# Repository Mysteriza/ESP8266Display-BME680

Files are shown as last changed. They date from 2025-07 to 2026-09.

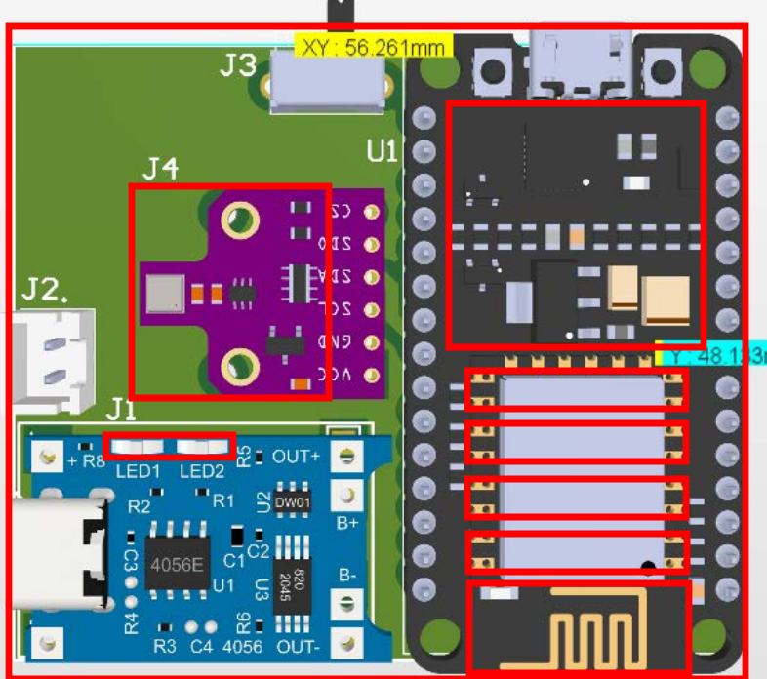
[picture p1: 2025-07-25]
Enclosure/Top Enclosure.png

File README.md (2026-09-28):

# High-Precision ESP8266 BME680 Environmental Monitor

A high-precision, portable environmental monitor using an ESP8266, a Bosch BME680 sensor, and an integrated OLED display. This project leverages the official **Bosch BSEC (Bosch Sensortec Environmental Cluster) software library** to provide accurate Indoor Air Quality (IAQ) readings, alongside temperature, humidity, pressure, and altitude.

The device is designed for **continuous operation** with robust error handling, intelligent baseline management, and an **always-on OLED display** that continuously cycles through data screens.



ESP8266 Device Front View
ESP8266 Device Side View
ESP8266 Device Rear View
ESP8266 Device Side View

---

## Key Features

### Core Sensing & IAQ

- **Bosch BSEC Integration:** Utilizes Bosch's proprietary BSEC algorithm for reliable **Indoor Air Quality (IAQ)** index calculation (0–500 scale).
- **Comprehensive Data:** Measures Temperature, Humidity, Barometric Pressure, Gas Resistance (VOCs), and calculates Altitude.
- **Data Persistence:** Saves the BSEC calibration state to EEPROM every **4 hours**, but only when the IAQ accuracy level is high (`iaqAccuracy==3`). This minimizes flash wear and ensures stable calibration across power cycles.

### Advanced Data Processing

- **Variance-Aware IAQ Smoothing:** Implements an adaptive smoothing algorithm on the Static IAQ value, providing a more stable and human-readable output.
- **Self-Adapting Gas Baseline:** Automatically adapts over time for long-term environmental stability.
- **Transport-Aware Logic:** Freezes baseline calibration when rapid environmental changes are detected (e.g., device movement).
- **Altitude Filtering:** Combines a median filter with an EMA for smooth and reliable altitude readings.

### Display & Power

- **Continuous Display Mode:** OLED display remains active 24/7, cycling through four data screens:
  - **Screen 1 (5s):** Temperature & Humidity
  - **Screen 2 (5s):** Pressure & Altitude
  - **Screen 3 (5s):** Gas Resistance, IAQ, Accuracy, Air Quality Status
  - **Screen 4 (5s):** System Uptime (HH:MM:SS)
- **Incremental Refresh:** Screen only updates when values change beyond thresholds, reducing flicker and CPU usage.
- **Battery Optimized:** Sensor reads every 30 seconds with intelligent power management for 24hr+ battery life.

### Overheat Protection

- If temperature ≥ **45°C**, device enters "HOT HOLD" mode.
- OLED shows a warning with a thermometer icon and the text **Overheat**, which shifts position every 60s to prevent burn-in.
- Normal operation resumes when temperature drops below **41°C**.

### Robustness

- **Error Recovery:** Auto-retry mechanism for BSEC initialization with exponential backoff.
- **Offline Operation:** Continues to work without network, using last known QNH or default fallback.
- **Serial Command Interface:** Configure QNH, check status, and calibrate altitude via serial monitor.

---

## Hardware Components

- **ESP8266 Board with Integrated OLED (0.96" SSD1306).**
- **Bosch BME680 Sensor** (I2C).
- **TP4056** for LiPo battery charging and management.
- **LiPo Battery** (e.g., 1500–2100 mAh).
- **Power Switch** for on/off control.
- **Custom PCB & Enclosure** for portability.

---

## Pin Configuration

| Component | Pin / Address |
| --- | --- |
| I2C SDA (Data) | `GPIO 14` |
| I2C SCL (Clock) | `GPIO 12` |
| OLED I2C Address | `0x3C` |
| BME680 I2C Address | `0x76` |

---

## Software Requirements

- Arduino IDE
- ESP8266 Board Package for Arduino IDE
- Libraries:
  - `Wire.h` (Built-in)
  - `EEPROM.h` (Built-in)
  - `Adafruit GFX Library`
  - `Adafruit SSD1306`
  - `Bosch BSEC Software Library`

---

## ⚠️ Important: IRAM Overflow Fix

If you encounter this compilation error:

```
section `.text1' will not fit in region `iram1_0_seg'
```

This is a **memory configuration issue**, not a code problem. The fix requires two settings changes:

### Quick Fix (Arduino IDE)

1. **Tools** → **Flash Size** → Change to `4M (3M SPIFFS)`
2. **Tools** → **MMU** → Select `16KB cache + 48KB IRAM`
3. **Restart Arduino IDE**

### Complete Guide

See **[FIX_IRAM_OVERFLOW_GUIDE.md](FIX_IRAM_OVERFLOW_GUIDE.md)** for:

- Detailed step-by-step instructions
- VS Code / PlatformIO configuration
- Manual `platform.txt` replacement method
- Troubleshooting and technical explanations

**Included in this project:** `platform.txt` (ready-to-use replacement file)

---

## Installation & Setup

1. **Install Arduino IDE & ESP8266 Core:**
   Add `http://arduino.esp8266.com/stable/package_esp8266com_index.json` to Board Manager URLs.

2. **Install Required Libraries** via Library Manager:
   - "Adafruit GFX Library"
   - "Adafruit SSD1306"
   - "BSEC Software Library"

3. **Configure the Sketch:**

   ```cpp
   // Edit configuration constants in config.h
   #define SENSOR_READ_INTERVAL_MS 30000UL    // Sensor reading interval
   #define OLED_DATA_SCREEN_1_DURATION 5000UL // Screen 1 duration
   #define OLED_DATA_SCREEN_2_DURATION 5000UL // Screen 2 duration
   #define OLED_DATA_SCREEN_3_DURATION 5000UL // Screen 3 duration
   #define OLED_DATA_SCREEN_4_DURATION 5000UL // Screen 4 (Uptime) duration
   ```

4. **Upload to ESP8266:**
   - Go to `Tools > Board` and select "NodeMCU 1.0 (ESP-12E Module)"
   - **Tools > Flash Size** → `4M (3M SPIFFS)`
   - **Tools > MMU** → `16KB cache + 48KB IRAM`
   - Connect your board and select the correct COM port
   - Click "Upload"

---

## Usage in the Field

### 🔹 Calibration via QNH (when local QNH data is available)

1. Connect your Android phone to the device via **USB-C OTG + data cable**.
2. Open **Serial USB Terminal** (or any compatible terminal app).
3. Set baud rate to **115200**, newline to **CR+LF**.
4. Type:
   ```
   QNH=1013.25
   ```
   (Adjust this to the latest QNH in your location. Check weather apps such as [Breezy Weather](https://github.com/breezy-weather/breezy-weather) for current atmospheric pressure)

The device stores QNH in EEPROM and immediately recalculates altitude.

### 🔹 Calibration via ALTREF (when you know the exact elevation)

1. Stand at a location with a verified elevation (e.g., summit, basecamp, map marker).
2. Type:
   ```
   ALTREF=709
   ```
   (Adjust this according to the altitude of your location)

The device computes QNH from the current pressure and saves it permanently. Verify with:

```
ALT?
```

### 🔹 Hiking / Trekking Scenario

- At **basecamp**, perform one calibration (QNH **or** ALTREF).
- Recalibrate if the weather changes significantly.
- **Precision Rule:** ±**1 hPa** ≈ ±**8–9 m** at mid-altitudes. Recalibrate whenever you change location or weather conditions vary.

---

## How It Works

### IAQ (Indoor Air Quality) Index

The BSEC library provides an IAQ value on a scale from 0 to 500:

- **0 - 50:** Excellent
- **51 - 100:** Good
- **101 - 150:** Lightly Polluted
- **151 - 200:** Moderately Polluted
- **201 - 300:** Heavily Polluted
- **301+:** Severely Polluted

The device displays this scale as an "AQS" (Air Quality Status) string for easy interpretation. The `Acc` (Accuracy) value indicates the BSEC algorithm's confidence level (0=stabilizing, 1=low, 2=medium, 3=high). High accuracy is typically achieved after the device runs for a while.

### Serial Commands

Connect via serial monitor (115200 baud) and use:

| Command | Description | Example Response |
| --- | --- | --- |
| `QNH=<hPa>`  | Set sea-level pressure | `OK QNH=1013.25 hPa` |
| `QNH?` | Query current QNH value | `QNH=1013.25 hPa` |
| `ALT?` | Query current altitude | `ALT=708.9 m` |
| `PRESS?` | Query current pressure | `P=933.10 hPa` |
| `ALTREF=<m>` | Auto-calculate QNH from known altitude | `OK QNH from ALTREF -> 1014.32 hPa` |
| `STATUS` | Show system status | `Mode:0 Therm:0 BSEC:Y IAQ:45.2(3)` |
| `HELP` | Show all commands | `CMD: QNH=<hPa>\|QNH?\|ALT?\|...` |

### Display Screens

The OLED continuously cycles through 4 screens:

1. **Screen 1 (5s):** Temperature & Humidity
2. **Screen 2 (5s):** Pressure & Altitude
3. **Screen 3 (5s):** Gas Resistance, IAQ, Accuracy, AQS
4. **Screen 4 (5s):** System Uptime (HH:MM:SS since boot)
5. **Loops back to Screen 1** → Continuous monitoring mode

### IAQ Scale

| IAQ Range | Air Quality |
| --- | --- |
| 0-50 | Excellent |
| 51-100 | Good |
| 101-150 | Light |
| 151-200 | Moderate |
| 201-300 | Unhealthy |
| 301+ | Hazardous |

### IAQ Accuracy

The `Acc` value (0-3) shows BSEC algorithm confidence:

- **0:** Stabilizing (first 5-30 minutes)
- **1:** Low confidence
- **2:** Medium confidence
- **3:** High confidence (optimal)

---

## Power Management

### Display Behavior

- **Continuous Mode:** Display never turns off
- **4 screens cycle** every 5 seconds each (20s total cycle)
- **Conditional redraw:** Only updates when values change beyond thresholds (reduces flicker)

### Battery Life Estimates

| Battery Capacity | Estimated Runtime |
| --- | --- |
| 1500 mAh | ~24-30 hours |
| 2000 mAh | ~30-36 hours |
| 2100 mAh | ~32-40 hours |

_Estimates based on continuous display mode with 30s sensor intervals_

---

## Advanced Features

### Thermal Protection

When temperature reaches **45°C**:

- Display shows animated "Overheat" warning
- Contrast reduced to minimum (prevents OLED damage)
- Warning icon position changes every 60s (prevents burn-in)
- Normal operation resumes at **41°C**

### Transport Detection

The device detects movement via rapid environmental changes:

- Freezes gas baseline calibration during transport
- Resumes calibration after 6 stable readings
- Prevents false VOC readings during relocation

### Adaptive IAQ Smoothing

IAQ display uses variance-adaptive filtering:

- **Low variance** (stable): Heavy smoothing (α=0.10) for stable reading
- **High variance** (changing): Light smoothing (α=0.45) for responsiveness
- **Accuracy-based:** Reduces smoothing when accuracy is low

---

## Accuracy Notes

- **Formula:** Based on the standard barometric equation. Real-world temperature deviations may cause small altitude offsets.
- **Sensor Tolerance:** BME680 pressure bias ≈ ±1 hPa → ±8–9 m error.
- **Weather Impact:** QNH drifts naturally with weather; recalibrate as needed during extended outdoor sessions.

---

## Troubleshooting

### ⚠️ IRAM Overflow Error (Compilation Error)

**Symptoms:**

```
section `.text1' will not fit in region `iram1_0_seg'
Compilation error: exit status 1
```

**Solution:** This is a memory configuration issue, NOT a code problem.

**Quick Fix:**

1. **Arduino IDE:**
   - Tools → Flash Size → Change to `4M (3M SPIFFS)`
   - Tools → MMU → Select `16KB cache + 48KB IRAM`
   - Restart Arduino IDE
2. **VS Code:**
   - Edit `.vscode/arduino.json`
   - Change `eesz=1M64` → `eesz=4M3M`
   - Change `mmu=3232` → `mmu=4816`
   - Reload window

**Complete Guide:** See [`FIX_IRAM_OVERFLOW_GUIDE.md`](FIX_IRAM_OVERFLOW_GUIDE.md) for detailed instructions and manual `platform.txt` replacement method.

### BSEC Initialization Fails

**Symptoms:** "Sensor Error" screen, "Retrying..."

**Solutions:**

1. Check I2C wiring (GPIO14=SDA, GPIO12=SCL)
2. Verify BME680 address (0x76 or 0x77)
3. Check serial monitor for error messages
4. Power cycle device

### IAQ Accuracy Stays at 0-1

**Cause:** BSEC needs time to stabilize

**Solution:** Leave device running for 30 minutes - 24 hours for full calibration

### Display Flickers

**Cause:** Normal when values change frequently

**Solution:** Adjust thresholds (`TH_T`, `TH_H`, etc.) to reduce update frequency

### EEPROM Corruption

**Symptoms:** Settings reset on reboot

**Solution:** Device auto-detects and repairs corrupted EEPROM

---

## Code Structure

```
ESP8266Display-BME680.ino   (setup + main loop)
└── src/
    ├── config.h             (all #defines, memory map)
    ├── types.h              (enumerations)
    ├── globals.h / .cpp     (global state variables)
    ├── utils.h / .cpp       (utility functions: baro, IAQ categories)
    ├── display/
    │   └── oled.h / .cpp    (OLED display + state machine)
    ├── sensing/
    │   ├── sensor.h / .cpp  (BSEC/BME680, thermal, error recovery)
    │   └── storage.h / .cpp (EEPROM persistence)
    └── communication/
        └── serial_cmd.h / .cpp (serial parser, char buffer)
```

---

## Project Files

| File | Description |
| --- | --- |
| `ESP8266Display-BME680.ino` | Main entry point (setup + loop) |
| `src/config.h` | Hardware & algorithm configuration constants |
| `src/types.h` | Enum type definitions |
| `src/globals.h` / `src/globals.cpp` | Global state variables |
| `src/utils.h` / `src/utils.cpp` | Utility functions (barometric, math, categories)  |
| `src/display/oled.h` / `src/display/oled.cpp` | OLED display & screen state machine |
| `src/sensing/sensor.h` / `src/sensing/sensor.cpp` | BSEC/BME680 driver, filtering, thermal, retry |
| `src/sensing/storage.h` / `src/sensing/storage.cpp` | EEPROM persistence layer |
| `src/communication/serial_cmd.h` / `src/communication/serial_cmd.cpp` | Serial parser (char buffer) |
| `platform.txt` | Fixed platform configuration for IRAM fix |
| `FIX_IRAM_OVERFLOW_GUIDE.md` | Complete IRAM overflow fix guide |
| `Pin.txt` | I2C wiring reference |
| `README.md` | This file - project documentation |

---

## Performance Metrics

### Memory Usage (Typical)

- **Flash:** ~290 KB code (measured build, varies with libraries)
- **SRAM:** ~34 KB (measured build)
- **EEPROM:** 512 bytes (~175 used: BSEC state + QNH + gas baseline)

### Timing

- **Boot Time:** ~2 seconds to first reading
- **BSEC Stabilization:** 5-30 minutes
- **Sensor Read Cycle:** 30 seconds
- **Display Cycle:** 20 seconds (4 screens, continuous loop)

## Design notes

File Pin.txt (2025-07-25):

I2C address 0x3C (OLED Display)

BME680 (0x76):
SDA = D5 / GPIO14
SCL = D6 / GPIO12
SDO = GND
CS = Not Connected

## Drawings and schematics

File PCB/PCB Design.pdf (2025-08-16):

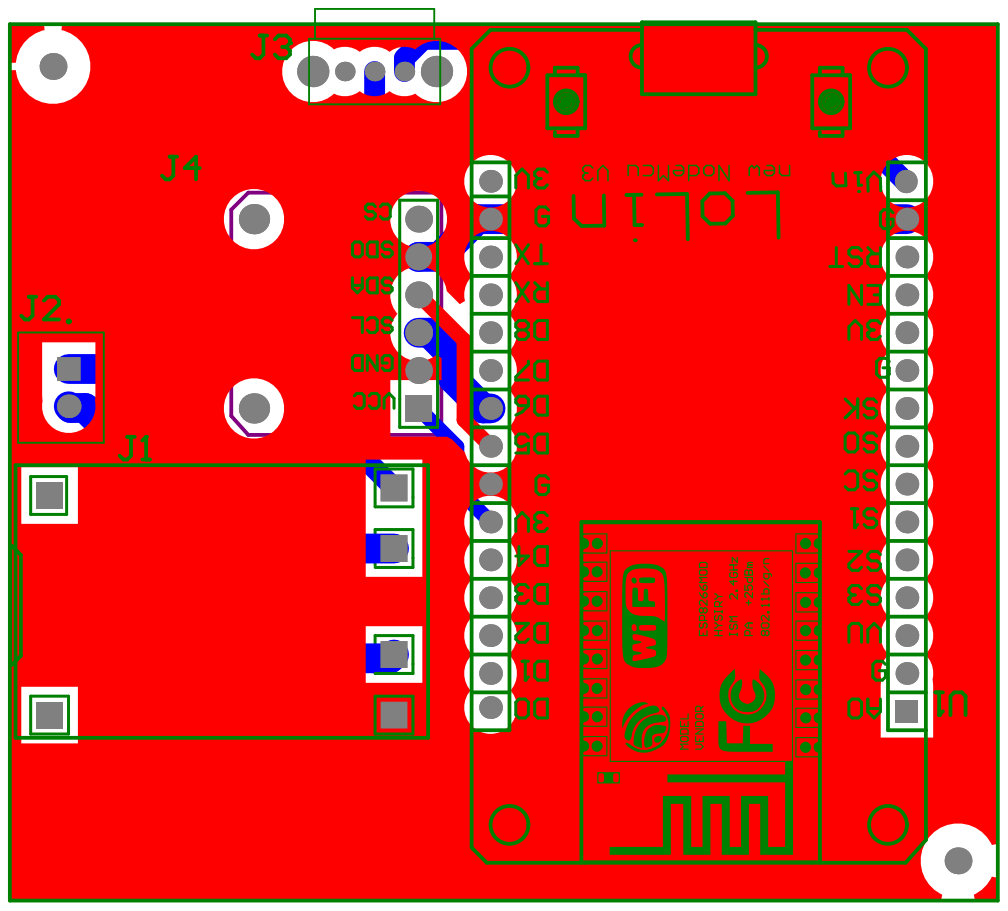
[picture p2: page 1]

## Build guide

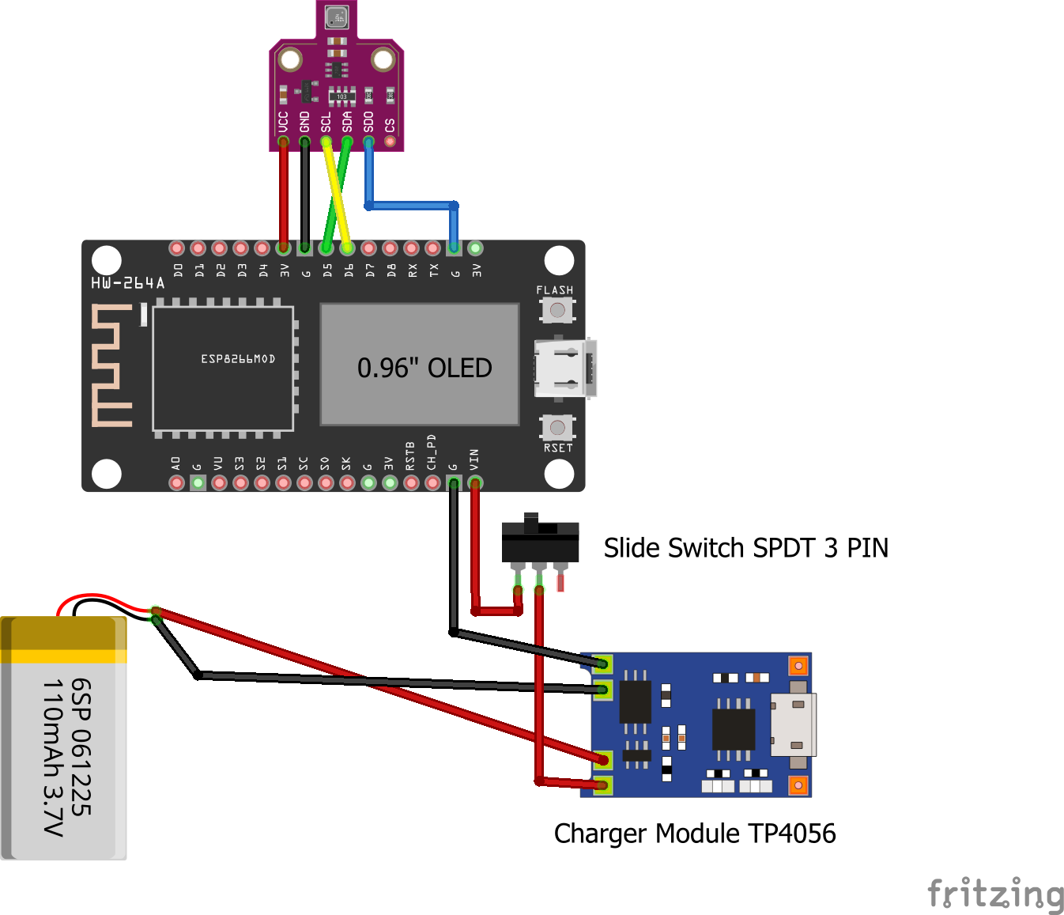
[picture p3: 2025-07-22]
PCB/Wiring ESP8266-BME680.png

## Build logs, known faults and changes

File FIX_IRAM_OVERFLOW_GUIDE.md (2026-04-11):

# ESP8266 IRAM Overflow Fix - Complete Guide

## Problem

When compiling ESP8266 projects with large libraries (especially **Bosch BSEC** for BME680), you get this error:

```
c:/users/.../xtensa-lx106-elf/bin/ld.exe: 
ESP8266Display-BME680.ino.elf section `.text1' will not fit in region `iram1_0_seg'
collect2.exe: error: ld returned 1 exit status
exit status 1
Compilation error: exit status 1
```

**Root Cause:** The ESP8266 has limited IRAM (Instruction RAM). The default configuration only allocates **32KB IRAM**, which is insufficient for large libraries like Bosch BSEC + Adafruit GFX + OLED drivers.

---

## Solution Overview

This fix requires **TWO changes**:

1. ✅ **Change Flash Size** → From 1MB to 4MB
2. ✅ **Change MMU Setting** → Enable 16KB Cache + 48KB IRAM

Both must be applied together for the fix to work.

---

## Method 1: Via Arduino IDE (Recommended for Beginners)

### Step 1: Change Flash Size

1. Open your project in **Arduino IDE**
2. Go to **Tools** menu
3. Find **Flash Size**
4. Change from `1M (64K SPIFFS)` → **`4M (3M SPIFFS)`** or `4M (1M SPIFFS)`

### Step 2: Change MMU Setting

1. Still in **Tools** menu
2. Find **MMU** (Memory Management Unit)
3. Select **`16KB cache + 48KB IRAM`** (sometimes labeled as `48KB IRAM, 16KB cache`)

### Step 3: Restart Arduino IDE

**Important:** You must restart Arduino IDE for changes to take effect.

### Step 4: Upload Again

Compile and upload your sketch. The IRAM overflow error should be resolved.

---

## Method 2: Via VS Code / PlatformIO (Advanced)

### Step 1: Update arduino.json

Open `.vscode/arduino.json` and change the `eesz` parameter:

**Before:**
```json
"configuration": "...eesz=1M64,mmu=3232..."
```

**After:**
```json
"configuration": "...eesz=4M3M,mmu=4816..."
```

**Key Changes:**
- `eesz=1M64` → `eesz=4M3M` (Flash: 1MB → 4MB)
- `mmu=3232` → `mmu=4816` (MMU: 32KB IRAM → 48KB IRAM)

### Step 2: Reload VS Code Window

Press `Ctrl+Shift+P` → Type "Reload Window" → Press Enter

### Step 3: Upload

Use Arduino CLI or upload normally.

---

## Method 3: Manual platform.txt Replacement (If Methods 1-2 Fail)

Sometimes the MMU option doesn't appear in Arduino IDE. This means you need to update the `platform.txt` file manually.

### Step 1: Locate platform.txt

Navigate to this folder (Windows):

```
C:\Users\<YOUR_USERNAME>\AppData\Local\Arduino15\packages\esp8266\hardware\esp8266\<VERSION>\
```

**Example:**
```
C:\Users\rifqi\AppData\Local\Arduino15\packages\esp8266\hardware\esp8266\3.1.2\
```

**macOS/Linux:**
```
~/.arduino15/packages/esp8266/hardware/esp8266/<VERSION>/
```

### Step 2: Backup Original

**IMPORTANT:** Before making changes, backup the original file!

```
Copy: platform.txt
To:   platform.txt.backup
```

### Step 3: Replace platform.txt

1. Open the `platform.txt` file provided in this project (included in project root)
2. Copy the **entire content**
3. Paste it into the original `platform.txt` at the Arduino15 location
4. Save the file

### Step 4: Verify MMU Options Appear

1. Open Arduino IDE
2. Go to **Tools** → **MMU**
3. You should now see these options:
   - `32KB cache + 32KB IRAM (balanced)` ← Default
   - **`16KB cache + 48KB IRAM`** ← **Select this one**
   - `No cache + 64KB IRAM (legacy)`

### Step 5: Select Correct MMU

Select: **`16KB cache + 48KB IRAM`**

### Step 6: Restart Arduino IDE

Close and reopen Arduino IDE completely.

### Step 7: Upload

Compile and upload. The error should be resolved.

---

## Complete Settings Summary

### For Arduino IDE:

| Setting | Value |
|---|---|
| **Board** | NodeMCU 1.0 (ESP-12E Module) |
| **Flash Size** | `4M (3M SPIFFS)` or `4M (1M SPIFFS)` |
| **MMU** | `16KB cache + 48KB IRAM` |
| **Upload Speed** | `115200` |
| **CPU Frequency** | `80 MHz` |
| **Flash Mode** | `DOUT` |
| **Flash Frequency** | `40 MHz` |
| **Debug Port** | `Disabled` |
| **Debug Level** | `None` |

### For VS Code (arduino.json):

```json
{
    "board": "esp8266:esp8266:generic",
    "configuration": "xtal=80,vt=flash,exception=disabled,stacksmash=disabled,ssl=all,mmu=4816,non32xfer=fast,ResetMethod=nodemcu,CrystalFreq=26,FlashFreq=40,FlashMode=dout,eesz=4M3M,led=2,sdk=nonosdk_190703,ip=lm2f,dbg=Disabled,lvl=None____,wipe=none,baud=115200",
    "port": "COM3",
    "sketch": "ESP8266Display-BME680.ino"
}
```

**Key parameters:**
- `eesz=4M3M` (Flash size)
- `mmu=4816` (48KB IRAM, 16KB cache)

---

## Troubleshooting

### Q: MMU option doesn't appear in Arduino IDE

**A:** Follow **Method 3** above to manually replace `platform.txt`.

### Q: Still getting IRAM overflow after applying fix

**A:** Verify these:
1. ✅ Flash Size = 4MB (not 1MB)
2. ✅ MMU = 16KB cache + 48KB IRAM
3. ✅ Restarted Arduino IDE after changes
4. ✅ Selected correct board (NodeMCU 1.0)

### Q: Will this damage my ESP8266?

**A:** **No.** These are safe configuration changes. Most ESP8266 modules have 4MB flash physically, but default to 1MB in software. This just unlocks the full capacity.

### Q: Can I use this fix for other large libraries?

**A:** **Yes!** This fix works for any library that causes IRAM overflow:
- Bosch BSEC
- TFT display libraries
- Audio libraries
- WiFi + MQTT combinations
- Large graphics libraries

### Q: What's the difference between MMU options?

| MMU Setting | IRAM | Cache | Best For |
|---|---|---|---|
| 32KB cache + 32KB IRAM | 32KB | 32KB | Small projects |
| **16KB cache + 48KB IRAM** | **48KB** | **16KB** | **Large libraries (BSEC, etc.)** |
| No cache + 64KB IRAM | 64KB | 0KB | Legacy code (not recommended) |

**Recommendation:** Use `16KB cache + 48KB IRAM` for most projects with BSEC.

---

## Technical Explanation

### What is IRAM?

**IRAM (Instruction RAM)** is where the ESP8266 stores code that needs to run quickly. It's limited to:
- **Default:** 32KB
- **With fix:** 48KB (50% more!)

### Why does BSEC need so much IRAM?

The Bosch BSEC library is a **precompiled binary** that contains:
- Sensor fusion algorithms
- IAQ calculation engine
- Calibration routines
- Temperature/humidity compensation

All of this requires significant memory.

### What does MMU do?

**MMU (Memory Management Unit)** controls how flash memory is mapped:
- **Cache:** Stores frequently-used code for faster access
- **IRAM:** Stores critical code that must run immediately

More IRAM = more space for large libraries.

---

## Credits

- **Original Solution:** ESP8266 Arduino Core community
- **Documented by:** rifqi
- **Tested with:** ESP8266 Core 3.1.2, Bosch BSEC Library
- **Date:** 2026-04-11

---

## Related Files

- `platform.txt` - Fixed platform configuration (can replace Arduino15 version)
- `Fix RAM ESP8266.txt` - Original fix notes
- `README.md` - Main project documentation

---

## License

This documentation is provided as-is for educational purposes.

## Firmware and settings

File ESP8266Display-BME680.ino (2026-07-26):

// ============================================================================
// ESP8266 BME680 Environmental Monitor
// Modular firmware: config.h | types.h | globals | utils | oled | sensor | storage | serial_cmd
// ============================================================================

#include <Wire.h>

#include "src/config.h"
#include "src/types.h"
#include "src/globals.h"
#include "src/utils.h"
#include "src/display/oled.h"
#include "src/sensing/storage.h"
#include "src/sensing/sensor.h"
#include "src/communication/serial_cmd.h"

// ============================================================================
// SETUP
// ============================================================================

void setup()
{
  Serial.begin(115200);
  Serial.println(F("\r\n=== ESP8266 BME680 Monitor v2.0 ==="));

  bootMs = millis();

  EEPROM.begin(EEPROM_SIZE);
  loadPersistent();

  Wire.begin(I2C_SDA_GPIO, I2C_SCL_GPIO);
  Wire.setClock(I2C_CLOCK_SLOW);
  delay(80);

  initOLED();

  if (!initBSEC())
  {
    currentAppMode = MODE_BME_ERROR;
    errorScreenDrawn = false;
    sensorRetryBackoffMs = 1000;
    nextSensorRetryMillis = millis() + sensorRetryBackoffMs;
    Serial.println(F("BSEC: init failed, will retry"));
  }
  else
  {
    Serial.println(F("BSEC: ready"));
  }

  Wire.setClock(I2C_CLOCK_FAST);
  lastSensorReadMillis = millis();
  oledScreenStateChangeMillis = millis();
  currentOledScreenState = OLED_STATE_DATA_SCREEN_1;
  display.ssd1306_command(SSD1306_DISPLAYON);
  display.clearDisplay();
  display.display();
  lastDrawnState = OLED_STATE_ERROR_SCREEN;

  Serial.println(F("Type HELP for commands"));
}

// ============================================================================
// MAIN LOOP
// ============================================================================

void loop()
{
  bsecLoopTick();

  if (currentAppMode == MODE_OFFLINE)
  {
    if (thermal == THERM_HOT_HOLD)
    {
      if (millis() >= nextSafetyProcessMs)
      {
        if (envData.temperature <= HOT_EXIT_C)
        {
          exitHotHold();
        }
        if (thermal == THERM_HOT_HOLD)
        {
          displayOverheat();
        }
        nextSafetyProcessMs = millis() + SAFETY_PERIOD_MS;
      }
    }
    else
    {
      if (millis() - lastSensorReadMillis >= SENSOR_READ_INTERVAL_MS)
      {
        readBME680SensorData();
        lastSensorReadMillis = millis();
      }
      updateOLEDDisplayContent();
    }
  }
  else if (currentAppMode == MODE_BME_ERROR)
  {
    handleSensorAutoRetry();
  }

  handleSerialInput();
  yield();
}

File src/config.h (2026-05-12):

#ifndef CONFIG_H
#define CONFIG_H

#include <bsec.h>

// I2C Configuration
#define I2C_SDA_GPIO 14
#define I2C_SCL_GPIO 12
#define I2C_CLOCK_SLOW 100000UL
#define I2C_CLOCK_FAST 400000UL

// Display Configuration
#define OLED_ADDRESS 0x3C
#define SCREEN_W 128
#define SCREEN_H 64
#define OLED_RESET -1

// Sensor Configuration
#define BME_ADDRESS 0x76
#define BME_HEALING_MS 5000

// Timing Configuration
#define SENSOR_READ_INTERVAL_MS 30000UL
#define OLED_DATA_SCREEN_1_DURATION 5000UL
#define OLED_DATA_SCREEN_2_DURATION 5000UL
#define OLED_DATA_SCREEN_3_DURATION 5000UL
#define OLED_DATA_SCREEN_4_DURATION 5000UL

// Power Management Thresholds
#define BATTERY_CRITICAL_MV 3200
#define BATTERY_LOW_MV 3500
#define BATTERY_NORMAL_MV 3700

// Thermal Protection
#define HOT_ENTER_C 45.0f
#define HOT_EXIT_C 41.0f
#define SAFETY_PERIOD_MS 60000UL

// BSEC Configuration
#define BSEC_SAVE_INTERVAL_MS 14400000UL
#define BSEC_MIN_SAVE_GAP_MS 600000UL
#define BSEC_BOOT_STABILIZATION_MS 300000UL

// IAQ Filtering
#define IAQ_VAR_ALPHA 0.10f
#define IAQ_DISPLAY_MIN_ACCURACY 2

// Gas Resistance Baseline
#define GAS_EMA_ALPHA 0.20f
#define BASELINE_ALPHA_UP 0.02f
#define BASELINE_ALPHA_DOWN 0.001f
#define GAS_BASELINE_READY_SAMPLES 2880

// Transport Detection
#define PORT_DECIM_N 10
#define PORT_BUF 24
#define PORT_TH_DP 3.5f
#define PORT_TH_DH 8.0f
#define PORT_TH_DIAQ 25.0f
#define PORT_RESUME_OK 6

// Altitude Filtering
#define ALT_EMA_ALPHA 0.12f
#define ALT_OUTLIER_M 18.0f
#define ALT_DEADBAND_M 0.40f

// Display Update Thresholds
#define TH_T 0.10f
#define TH_H 0.10f
#define TH_P 0.10f
#define TH_ALT 1.0f
#define TH_G 0.10f
#define TH_IAQ 0.50f

// OLED Contrast
#define CONTRAST_NORMAL 0x7F
#define CONTRAST_OVERHEAT 0x04

// EEPROM Memory Map
#define EEPROM_SIZE 512
#define EEPROM_MAGIC_ADDR 0
#define EEPROM_MAGIC_VALUE 0xB6680A11
#define SEA_LEVEL_PRESSURE_ADDR 4
#define GAS_BASELINE_ADDR 8
#define GAS_BASELINE_READY_ADDR 12
#define BSEC_STATE_ADDR 16
#define BSEC_STATE_MAXLEN BSEC_MAX_STATE_BLOB_SIZE
#define BSEC_STATE_VALID_ADDR (BSEC_STATE_ADDR + BSEC_STATE_MAXLEN)
#define BSEC_STATE_VALID_MAGIC 0xB5EC1A0F

// Boot and timeout constants
#define BOOT_GRACE_MS 60000UL
#define NO_DATA_TIMEOUT_BOOT_MS 45000UL
#define NO_DATA_TIMEOUT_RUN_MS 20000UL

#endif

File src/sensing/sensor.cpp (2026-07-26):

#include "sensor.h"
#include "../globals.h"
#include "../utils.h"
#include "storage.h"
#include "../display/oled.h"

bool initBSEC()
{
  Wire.beginTransmission(BME_ADDRESS);
  Wire.write(0xE0);
  Wire.write(0xB6);
  Wire.endTransmission();
  delay(10);

  iaqSensor.begin(BME_ADDRESS, Wire);
  if (iaqSensor.bsecStatus < BSEC_OK || iaqSensor.bme68xStatus != BME68X_OK)
  {
    return false;
  }

  bsec_virtual_sensor_t list[] = {
      BSEC_OUTPUT_IAQ,
      BSEC_OUTPUT_STATIC_IAQ,
      BSEC_OUTPUT_SENSOR_HEAT_COMPENSATED_TEMPERATURE,
      BSEC_OUTPUT_SENSOR_HEAT_COMPENSATED_HUMIDITY,
      BSEC_OUTPUT_RAW_PRESSURE,
      BSEC_OUTPUT_RAW_GAS};
  iaqSensor.updateSubscription(list, sizeof(list) / sizeof(list[0]), BSEC_SAMPLE_RATE_LP);
  if (iaqSensor.bsecStatus < BSEC_OK || iaqSensor.bme68xStatus != BME68X_OK)
  {
    return false;
  }

  loadBsecState();
  lastBsecSaveMs = millis();
  envData.iaqAccuracyPrev = iaqSensor.iaqAccuracy;
  envData.iaqAccuracyDisp = envData.iaqAccuracyPrev;

  bsecActive = true;
  bsecHasData = false;
  return true;
}

void resetAltitudeFiltering()
{
  gAltSmooth = NAN;
  altRaw3[0] = NAN;
  altRaw3[1] = NAN;
  altRaw3[2] = NAN;
  altIdx = 0;
  altCnt = 0;
  lastDrawnState = OLED_STATE_ERROR_SCREEN;
}

void setQNH(float qnh)
{
  if (qnh >= 870.0f && qnh <= 1100.0f)
  {
    seaLevelPressure_hPa_current = qnh;
    saveSeaLevelPressure(qnh);
    resetAltitudeFiltering();
  }
}

void calQNHFromAltRef(float href_m)
{
  if (!(href_m > -1000.0f && href_m < 10000.0f))
    return;
  float q = qnhFromRef(envData.pressure, href_m);
  if (isfinite(q) && q >= 870.0f && q <= 1100.0f)
  {
    setQNH(q);
  }
}

void bsecLoopTick()
{
  if (!bsecActive)
    return;
  if (!iaqSensor.run())
    return;

  envData.iaq = iaqSensor.iaq;
  envData.iaqStatic = iaqSensor.staticIaq;
  envData.iaqAccuracy = iaqSensor.iaqAccuracy;
  envData.temperature = iaqSensor.temperature;
  envData.humidity = iaqSensor.humidity;
  envData.pressure = iaqSensor.pressure / 100.0f;
  envData.gasResistance = iaqSensor.gasResistance / 1000.0f;

  // Altitude calculation with median + EMA filtering
  float alt_raw = temperatureCompensatedAltitude(envData.pressure, seaLevelPressure_hPa_current, envData.temperature);
  altRaw3[altIdx] = alt_raw;
  altIdx = (altIdx + 1) % 3;
  if (altCnt < 3)
    altCnt++;

  float med = (altCnt >= 3) ? med3(altRaw3[0], altRaw3[1], altRaw3[2]) : alt_raw;
  if (fabsf(alt_raw - med) > ALT_OUTLIER_M)
  {
    alt_raw = med;
  }

  if (isnan(gAltSmooth))
  {
    gAltSmooth = alt_raw;
  }
  else
  {
    float cand = ALT_EMA_ALPHA * alt_raw + (1.0f - ALT_EMA_ALPHA) * gAltSmooth;
    if (fabsf(cand - gAltSmooth) >= ALT_DEADBAND_M)
    {
      gAltSmooth = cand;
    }
  }
  envData.altitude = gAltSmooth;

  if (!bsecHasData)
    lastDrawnState = OLED_STATE_ERROR_SCREEN;
  bsecHasData = true;
  lastBsecDataMs = millis();

  // Gas resistance EMA filtering
  if (isnan(envData.gasResistanceEMA))
  {
    envData.gasResistanceEMA = envData.gasResistance;
  }
  else
  {
    envData.gasResistanceEMA = GAS_EMA_ALPHA * envData.gasResistance + (1.0f - GAS_EMA_ALPHA) * envData.gasResistanceEMA;
  }

  // IAQ variance-adaptive smoothing
  if (isnan(iaqMeanEWMA))
  {
    iaqMeanEWMA = envData.iaqStatic;
    iaqVarEWMA = 0.0f;
  }
  float d = envData.iaqStatic - iaqMeanEWMA;
  iaqMeanEWMA += IAQ_VAR_ALPHA * d;
  iaqVarEWMA = (1.0f - IAQ_VAR_ALPHA) * (iaqVarEWMA + IAQ_VAR_ALPHA * d * d);
  float vol = sqrtf(fmaxf(iaqVarEWMA, 0.0f));

  float aVar;
  if (vol <= 2.0f)
    aVar = 0.10f;
  else if (vol >= 25.0f)
    aVar = 0.45f;
  else
    aVar = 0.10f + (vol - 2.0f) * (0.35f / (25.0f - 2.0f));

  if (envData.iaqAccuracy >= 3)
    aVar *= 0.6f;
  if (envData.iaqAccuracy <= 1)
    aVar = fmaxf(aVar, 0.28f);
  aVar = fminf(fmaxf(aVar, 0.08f), 0.45f);

  if (isnan(envData.iaqStaticDisp))
  {
    envData.iaqStaticDisp = envData.iaqStatic;
  }
  else
  {
    envData.iaqStaticDisp = aVar * envData.iaqStatic + (1.0f - aVar) * envData.iaqStaticDisp;
  }

  // Periodic BSEC state save
  if (millis() - lastBsecSaveMs >= BSEC_SAVE_INTERVAL_MS && envData.iaqAccuracy >= 3)
  {
    saveBsecState();
    lastBsecSaveMs = millis();
  }

  if (envData.iaqAccuracy > envData.iaqAccuracyPrev && envData.iaqAccuracy >= 2)
  {
    if (millis() - lastBsecSaveMs >= BSEC_MIN_SAVE_GAP_MS)
    {
      saveBsecState();
      lastBsecSaveMs = millis();
    }
  }

  envData.iaqAccuracyDisp = (envData.iaqAccuracy >= 3) ? 3 : (envData.iaqAccuracy == 2 && envData.iaqAccuracyDisp == 3 ? 2 : envData.iaqAccuracy);
  envData.iaqAccuracyPrev = envData.iaqAccuracy;

  // Transport detection
  if (++portDecim >= PORT_DECIM_N)
  {
    portDecim = 0;
    portBufP[portW] = envData.pressure;
    portBufH[portW] = envData.humidity;
    portBufI[portW] = envData.iaqStatic;
    portW = (portW + 1) % PORT_BUF;
    if (portFill < PORT_BUF)
      portFill++;

    if (portFill >= 2)
    {
      int newest = (portW + PORT_BUF - 1) % PORT_BUF;
      int oldest = (portFill == PORT_BUF) ? portW : 0;
      float dP = portBufP[newest] - portBufP[oldest];
      float dH = portBufH[newest] - portBufH[oldest];
      float dI = portBufI[newest] - portBufI[oldest];
      bool moving = (fabsf(dP) > PORT_TH_DP) || (fabsf(dH) > PORT_TH_DH) || (fabsf(dI) > PORT_TH_DIAQ);

      if (moving)
      {
        baselineFrozen = true;
        portStableCount = 0;
      }
      else
      {
        if (baselineFrozen)
        {
          if (++portStableCount >= PORT_RESUME_OK)
          {
            baselineFrozen = false;
          }
        }
      }
    }
  }
}

void readBME680SensorData()
{
  if (!bsecActive)
    return;

  unsigned long noDataTimeout = (millis() - bootMs < BOOT_GRACE_MS) ? NO_DATA_TIMEOUT_BOOT_MS : NO_DATA_TIMEOUT_RUN_MS;
  if (!bsecHasData || (millis() - lastBsecDataMs > noDataTimeout))
  {
    currentAppMode = MODE_BME_ERROR;
    errorScreenDrawn = false;
    display.clearDisplay();
    display.display();
    sensorRetryBackoffMs = 1000;
    nextSensorRetryMillis = millis() + sensorRetryBackoffMs;
    return;
  }

  if (!baselineFrozen)
  {
    if (isnan(gasBaseline_kOhm))
    {
      gasBaseline_kOhm = envData.gasResistanceEMA;
    }
    float dv = envData.gasResistanceEMA - gasBaseline_kOhm;
    gasBaseline_kOhm += (dv > 0 ? BASELINE_ALPHA_UP : BASELINE_ALPHA_DOWN) * dv;
  }

  gasSampleCounter++;
  if (!gasBaselineReady && gasSampleCounter >= GAS_BASELINE_READY_SAMPLES)
  {
    gasBaselineReady = true;
    saveGasBaseline(gasBaseline_kOhm, true);
  }

  if (thermal == THERM_NORMAL && envData.temperature >= HOT_ENTER_C)
  {
    enterHotHold();
    return;
  }
  if (thermal == THERM_HOT_HOLD && envData.temperature <= HOT_EXIT_C)
  {
    exitHotHold();
  }

  lastDrawnState = OLED_STATE_ERROR_SCREEN;
}

void enterHotHold()
{
  thermal = THERM_HOT_HOLD;
  oledSetContrast(CONTRAST_OVERHEAT);
  displayOverheat();
  nextSafetyProcessMs = millis();
}
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

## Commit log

2025-07-22 Refactor code structure for improved readability and maintainability
    [Wiring.fzz]
2025-08-16 Add Gerber files and status report for Rifqi project outputs
    - Created new Gerber files for mechanical layers, pads, soldermask, and paste for both top and bottom layers.
    - Included a profile Gerber file for the project.
    - Generated NC drill files and updated the status report with details of the output generation.
    - All files generated using Altium Designer version 24.6.1.
    [Rifqi_Copper_Signal_Bot.gbr, Rifqi_Copper_Signal_Top.gbr, Rifqi_Keep-out.gbr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]
2025-08-16 Refactor BME680 sensor handling and improve OLED display management
2025-08-16 Implement auto-retry mechanism for BME680 sensor and refactor Open-Meteo path handling
2025-08-19 Refactor code structure for improved readability and update BSEC integration for enhanced sensor handling
2025-10-11 Implement feature X to enhance user experience and fix bug Y in module Z
    [ESP8266Display-BME680.ino]
2026-04-11 Add comprehensive guide and platform configuration for ESP8266 IRAM overflow fix
    - Introduced FIX_IRAM_OVERFLOW_GUIDE.md detailing steps to resolve IRAM overflow errors when using large libraries like Bosch BSEC.
    - Added platform.txt to enable 16KB cache and 48KB IRAM settings for improved memory management.
    - Included troubleshooting tips and configuration summaries for both Arduino IDE and VS Code users.
    [ESP8266Display-BME680.ino]
2026-05-12 Add serial command handling, OLED display management, and sensor integration
    - Implemented serial command handling in `serial_cmd.cpp` to manage QNH, altitude, pressure, and status queries.
    - Created `serial_cmd.h` for function declarations related to serial command handling.
    - Added configuration settings in `config.h` for I2C, display, sensor, and power management.
    - Developed OLED display functions in `oled.cpp` and `oled.h` for initializing the display, setting contrast, and displaying various screens.
    - Introduced global variables in `globals.cpp` and `globals.h` to manage application state, sensor data, and display state.
    - Implemented sensor management in `sensor.cpp` and `sensor.h`,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
2026-07-26 Refactor sensor data handling to use EnvironmentData structure and update display functions accordingly
2026-09-21 Add periodic WiFi QNH auto-sync with battery-friendly radio windows
    - New wifi_qnh module: radio stays OFF, wakes hourly for ~5s to fetch
    current.pressure_msl from Open-Meteo over plain HTTP (no TLS: IRAM
    budget), manual HTTP client with zero-String parsing, then sleeps
    - 3x burst retry per sync window (15s each), 15min retry on failure,
    TX power reduced to 10dBm for battery and brownout safety
    - QNH policy: manual QNH/ALTREF wins and freezes auto-sync; 0.4 hPa
    deadband against API jitter; source (AUTO/MAN/DEF) persisted in EEPROM
    - Uptime screen shows live QNH value plus sync age (SYNC NOW/10m AGO),
    WIFI WAIT, SYNC FAIL states; all rows verified within 64px, no clip
    - Serial provi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
    [ESP8266Display-BME680.ino, config.h, sensor.cpp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]
2026-09-26 Add multi-network WiFi with scan-match selection
    - Store up to 3 networks (slot priority); each sync window scans for
    known SSIDs first, connects in priority order, max 3 tries per minute
    - Hidden-SSID fallback: blind slot-0 attempt when scan matches nothing
    - Track and report last used AP (via=) in WIFI? status
    - EEPROM expanded to 1024B with NET2/NET3 blocks; legacy layout intact
    - New serial commands WIFI2_SSID/PASS, WIFI3_SSID/PASS; multi-slot WIFI?
    - Verified live: scan-matched Kosan bu nata, fetched and auto-applied
    QNH=1011.20 (deadband exceeded), altitude filter reset
    [config.h, serial_cmd.cpp]
2026-09-26 Audit fixes: header FIN race, honest QNH rejection
    - wifi_qnh: don't abort header read on early FIN; ESP8266
    connected() can report false while final packet in flight,
    deadline already bounds the loop
    - setQNH returns bool; serial QNH= prints ERR QNH 870..1100 on
    reject instead of misleading OK with unchanged value
    [sensor.cpp, serial_cmd.cpp]
2026-09-27 Add zero-cost QNH trend arrows and storm alert
    - Record every fetched QNH into persisted 6-sample history ring
    - Altitude line shows ^/v/~ hourly trend; serial logs rate (+x.x/h)
    - WX ALERT on serial when pressure falls faster than 1.0 hPa/h
    - No extra radio, battery, or libraries: reuses hourly fetch data
2026-09-27 Revert "Add zero-cost QNH trend arrows and storm alert"
    This reverts commit 81ad1810008b858492fe4057ba801de5165ee081.
    [config.h]
2026-09-28 Revert WiFi QNH auto-sync feature (battery drain)
    Removes periodic WiFi, Open-Meteo fetch, multi-network support, and
    all related config, storage, serial, display, and docs changes.
    Device returns to offline-only operation for maximum battery life.
    Note: .vscode/arduino.json keeps mmu=4816 per FIX_IRAM_OVERFLOW_GUIDE
    (pre-existing project requirement, verified: mmu=3232 fails to link
    even without WiFi code).
    [ESP8266Display-BME680.ino, config.h, sensor.cpp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]
